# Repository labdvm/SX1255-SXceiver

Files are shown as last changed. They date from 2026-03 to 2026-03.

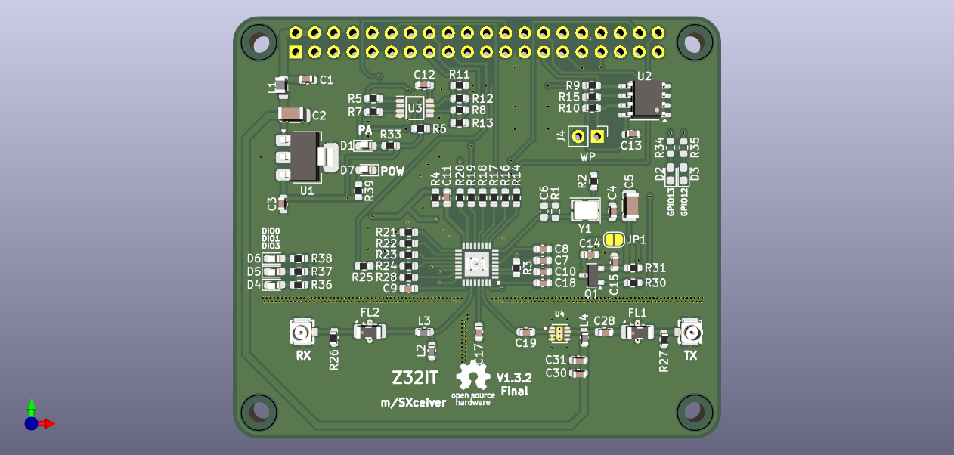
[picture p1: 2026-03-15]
SX1255-SXCEIVER-HAT.png

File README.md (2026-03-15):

# SX1255-SXceiver-HAT
This is modified SXceiver by shared schematic from Tatu Peltola.
SX1255 HAT for RPi4-5.
# Main SX-HAT is with (LowPass filters, PA and IPX connectors), second one is with (BandPass filters, PA and SMA connectors) and thirt one is with BandPass filters, ceramic antennas and without PA.
# RPi4/5 with minimum 2GB RAM, fast-write micro-sd card or upgraded with M.2 nvme drive.
# The eeprom is for HW-ID and if cannot be programmed by the procedures then you must programm with eeprom programmator. " https://github.com/tejeez/sxxcvr/blob/main/dts/README.md ".
# For Tetra-TMO Base Station this is the installing procedures, " https://github.com/MidnightBlueLabs/tetra-bluestation-docs/wiki ".
https://github.com/MidnightBlueLabs/tetra-bluestation

# The PA (TQP3M9036) can amplify up to 20dBm @ (70cm-band) 
# BlueStation Tetra TMO configurator " https://dimetra.russel053.com/ "
# Z32IT

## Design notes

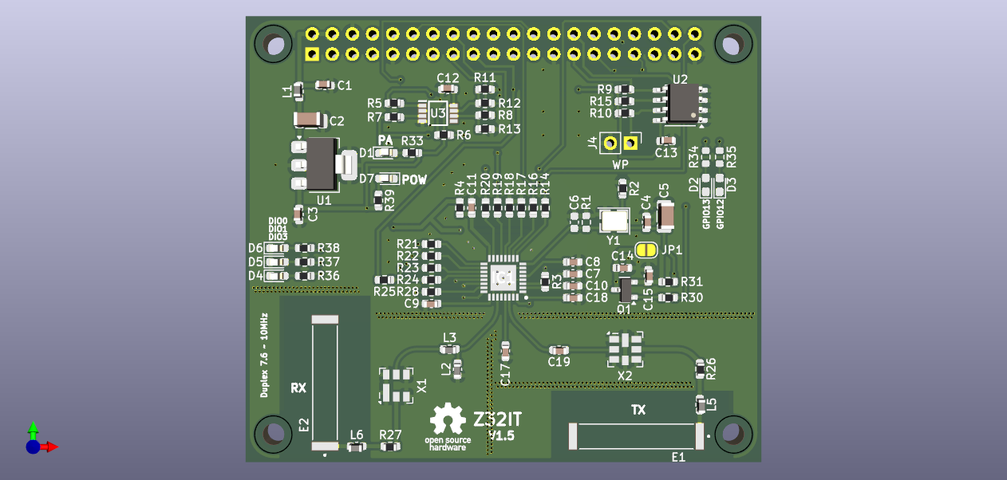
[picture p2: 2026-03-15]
SX1255-SXCEIVER-HAT_microspot/SX1255-SXCEIVER-HAT_microspot.png

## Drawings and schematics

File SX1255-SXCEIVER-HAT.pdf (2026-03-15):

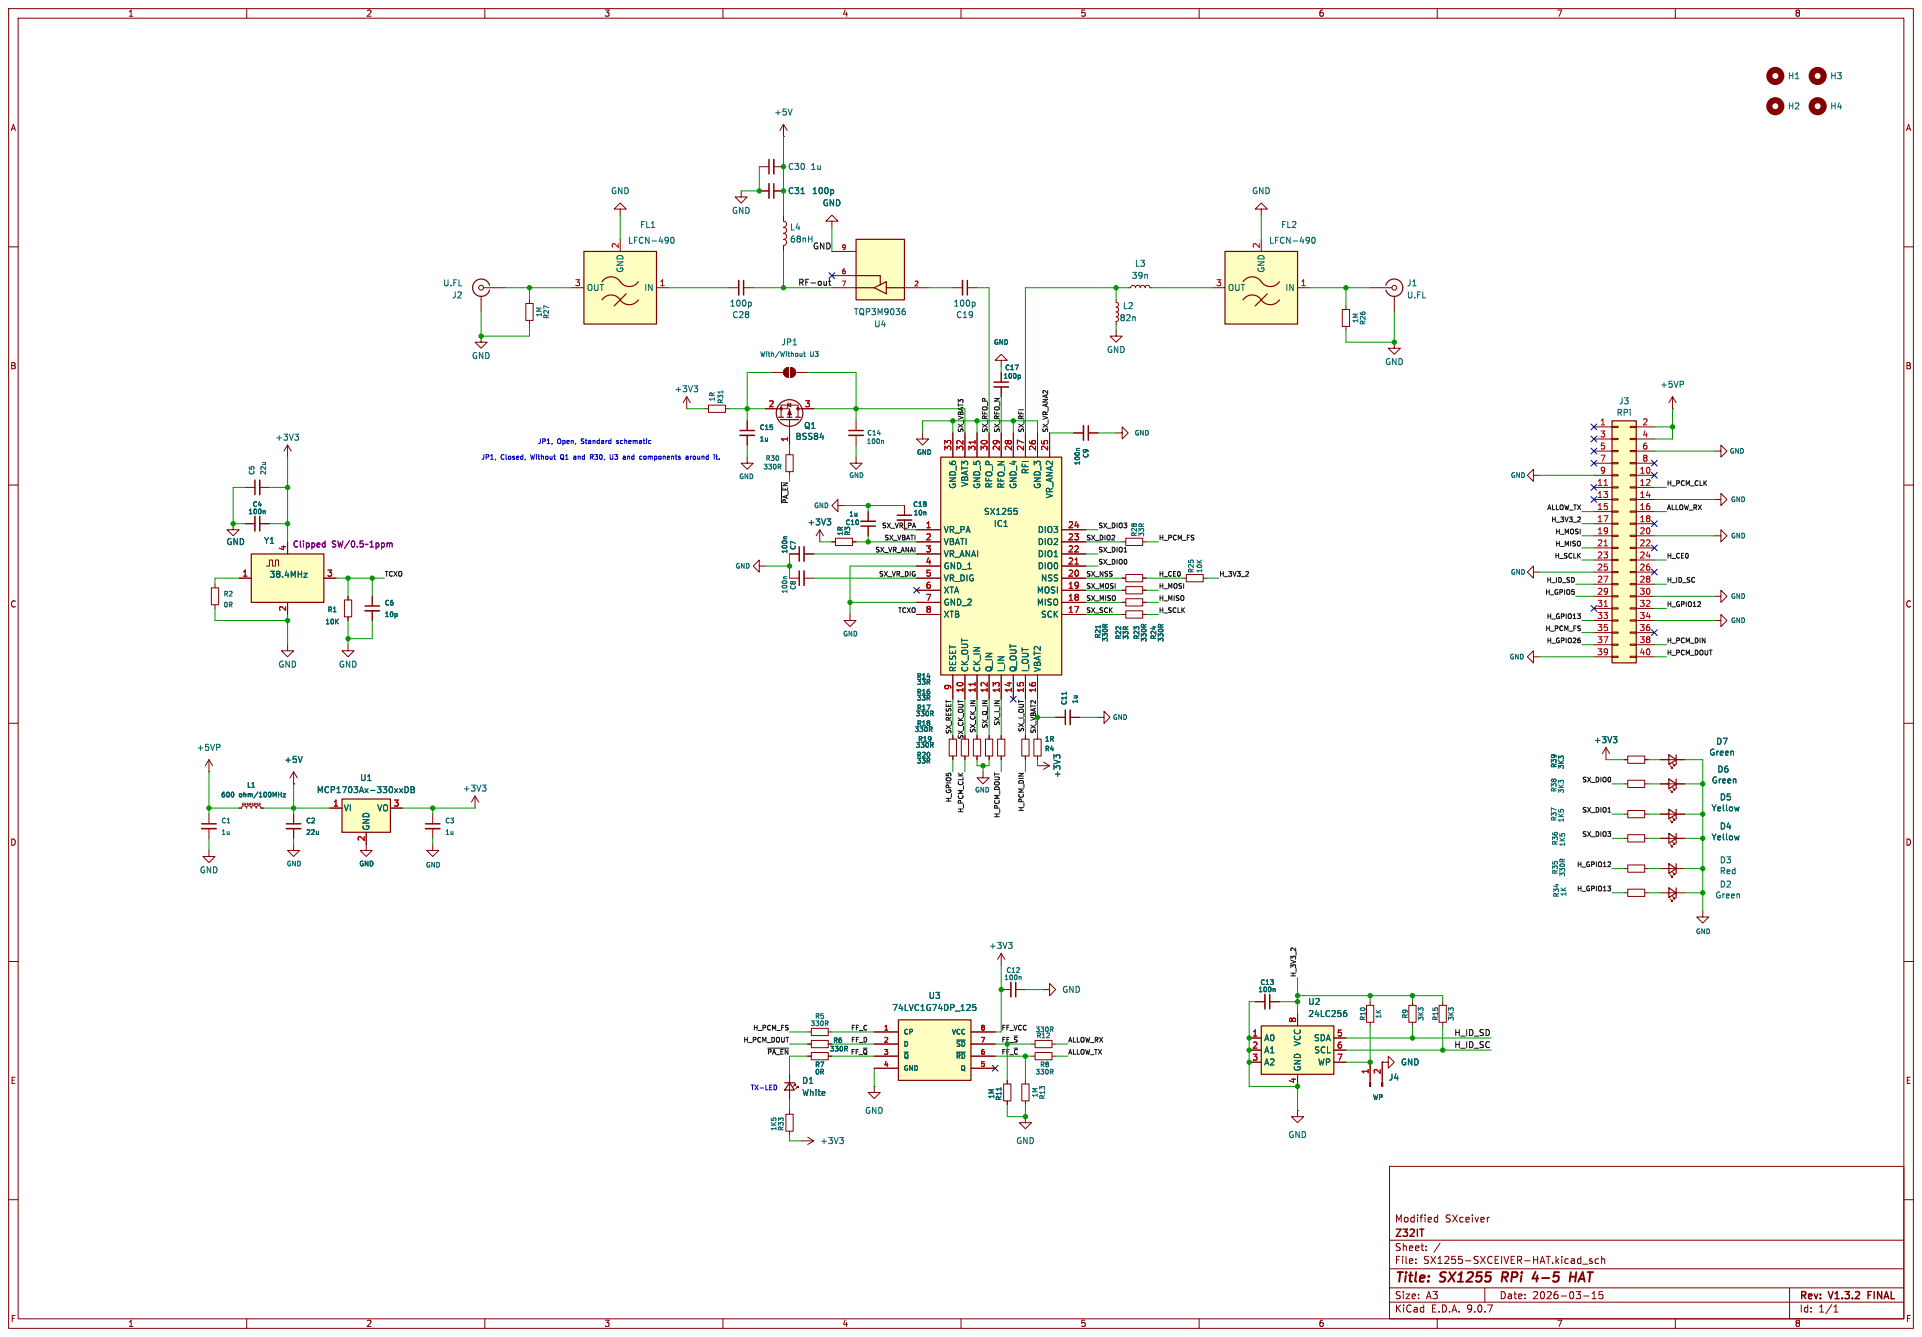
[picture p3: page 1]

9 VBAT3 32 CK_OUT 10 GND_5 31 CK_IN 11 RFO_P 30 Q_IN 12 RFO_N 29 I_IN 13 GND_4 28 Q_OUT 14 RFI 27 I_OUT 15 GND_3 26 VBAT2 16 VR_ANA2 25 DIO3 24 DIO2 23 DIO1 22 DIO0 21 NSS 20 MOSI 19 MISO 18 SCK 17

9 VBAT3 32 CK_OUT 10 GND_5 31 CK_IN 11 RFO_P 30 Q_IN 12 RFO_N 29 I_IN 13 GND_4 28 Q_OUT 14 RFI 27 I_OUT 15 GND_3 26 VBAT2 16 VR_ANA2 25 DIO3 24 DIO2 23 DIO1 22 DIO0 21 NSS 20 MOSI 19 MISO 18 SCK 17 C9 100n R23 R22 33R 330R R24 330R R21 330R GND

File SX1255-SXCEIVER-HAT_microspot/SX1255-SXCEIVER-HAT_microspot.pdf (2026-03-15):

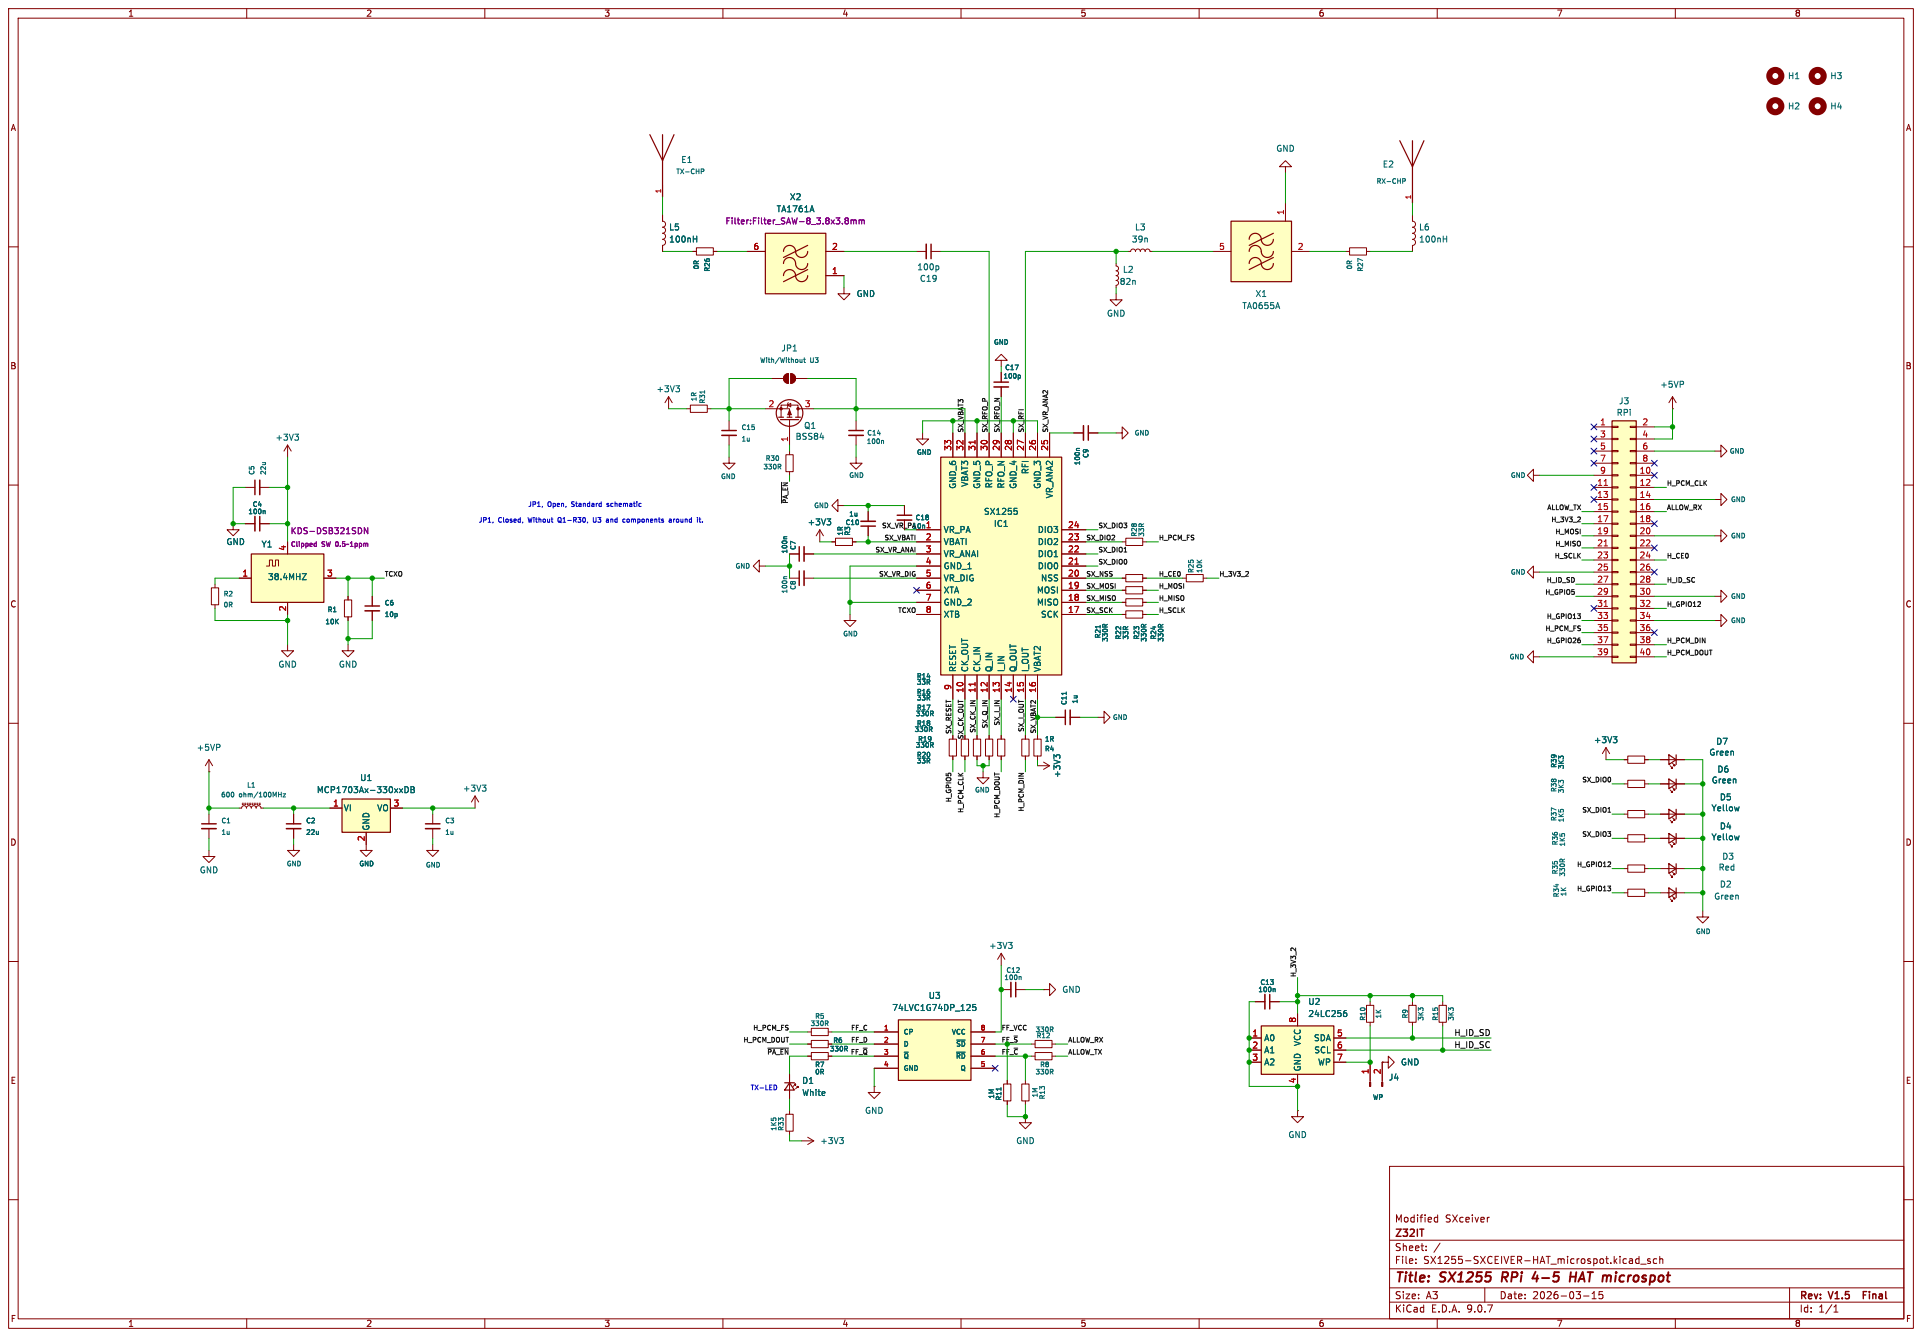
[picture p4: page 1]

9 VBAT3 32 CK_OUT 10 GND_5 31 CK_IN 11 RFO_P 30 Q_IN 12 RFO_N 29 I_IN 13 GND_4 28 Q_OUT 14 RFI 27 I_OUT 15 GND_3 26 VBAT2 16 VR_ANA2 25 DIO3 24 DIO2 23 DIO1 22 DIO0 21 NSS 20 MOSI 19 MISO 18 SCK 17 R17

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

Clipped SW 0.5~1ppm KDS-DSB321SDN GND
3 GND

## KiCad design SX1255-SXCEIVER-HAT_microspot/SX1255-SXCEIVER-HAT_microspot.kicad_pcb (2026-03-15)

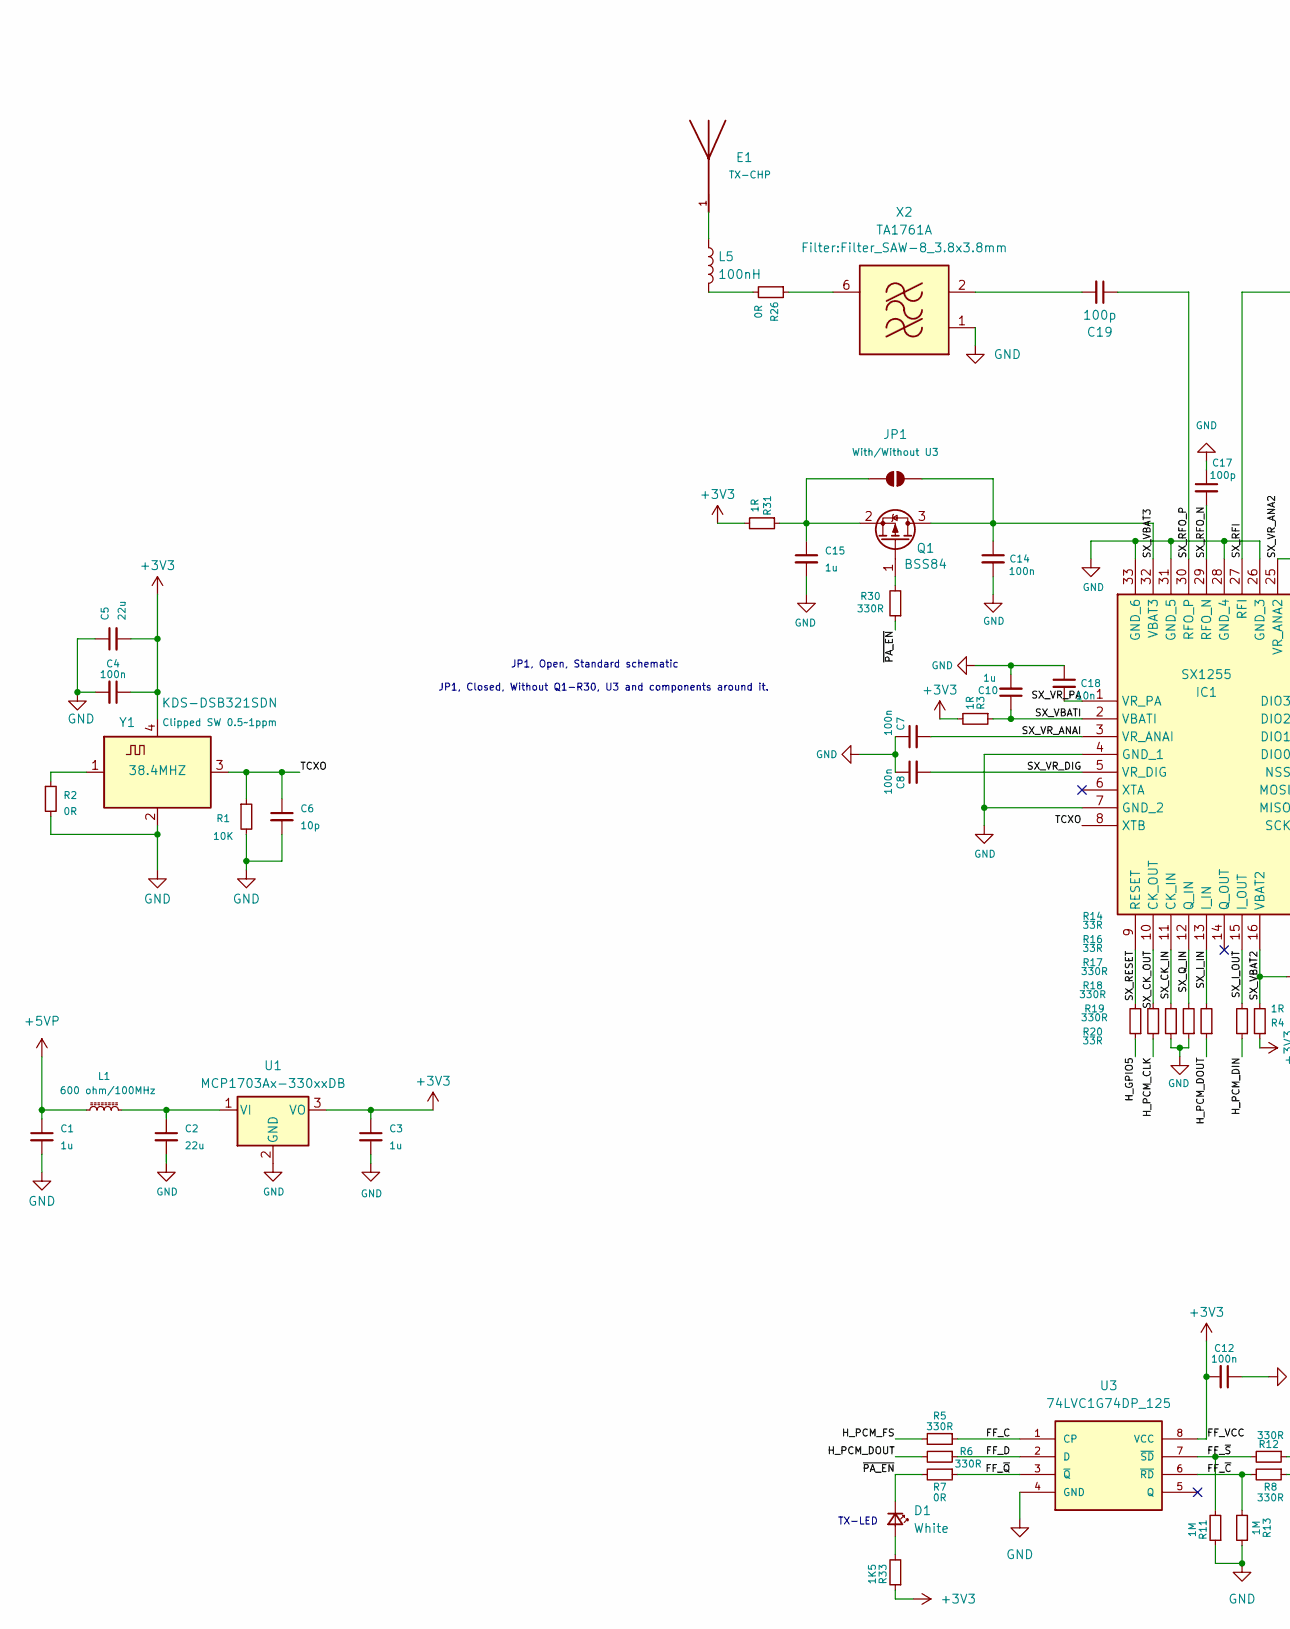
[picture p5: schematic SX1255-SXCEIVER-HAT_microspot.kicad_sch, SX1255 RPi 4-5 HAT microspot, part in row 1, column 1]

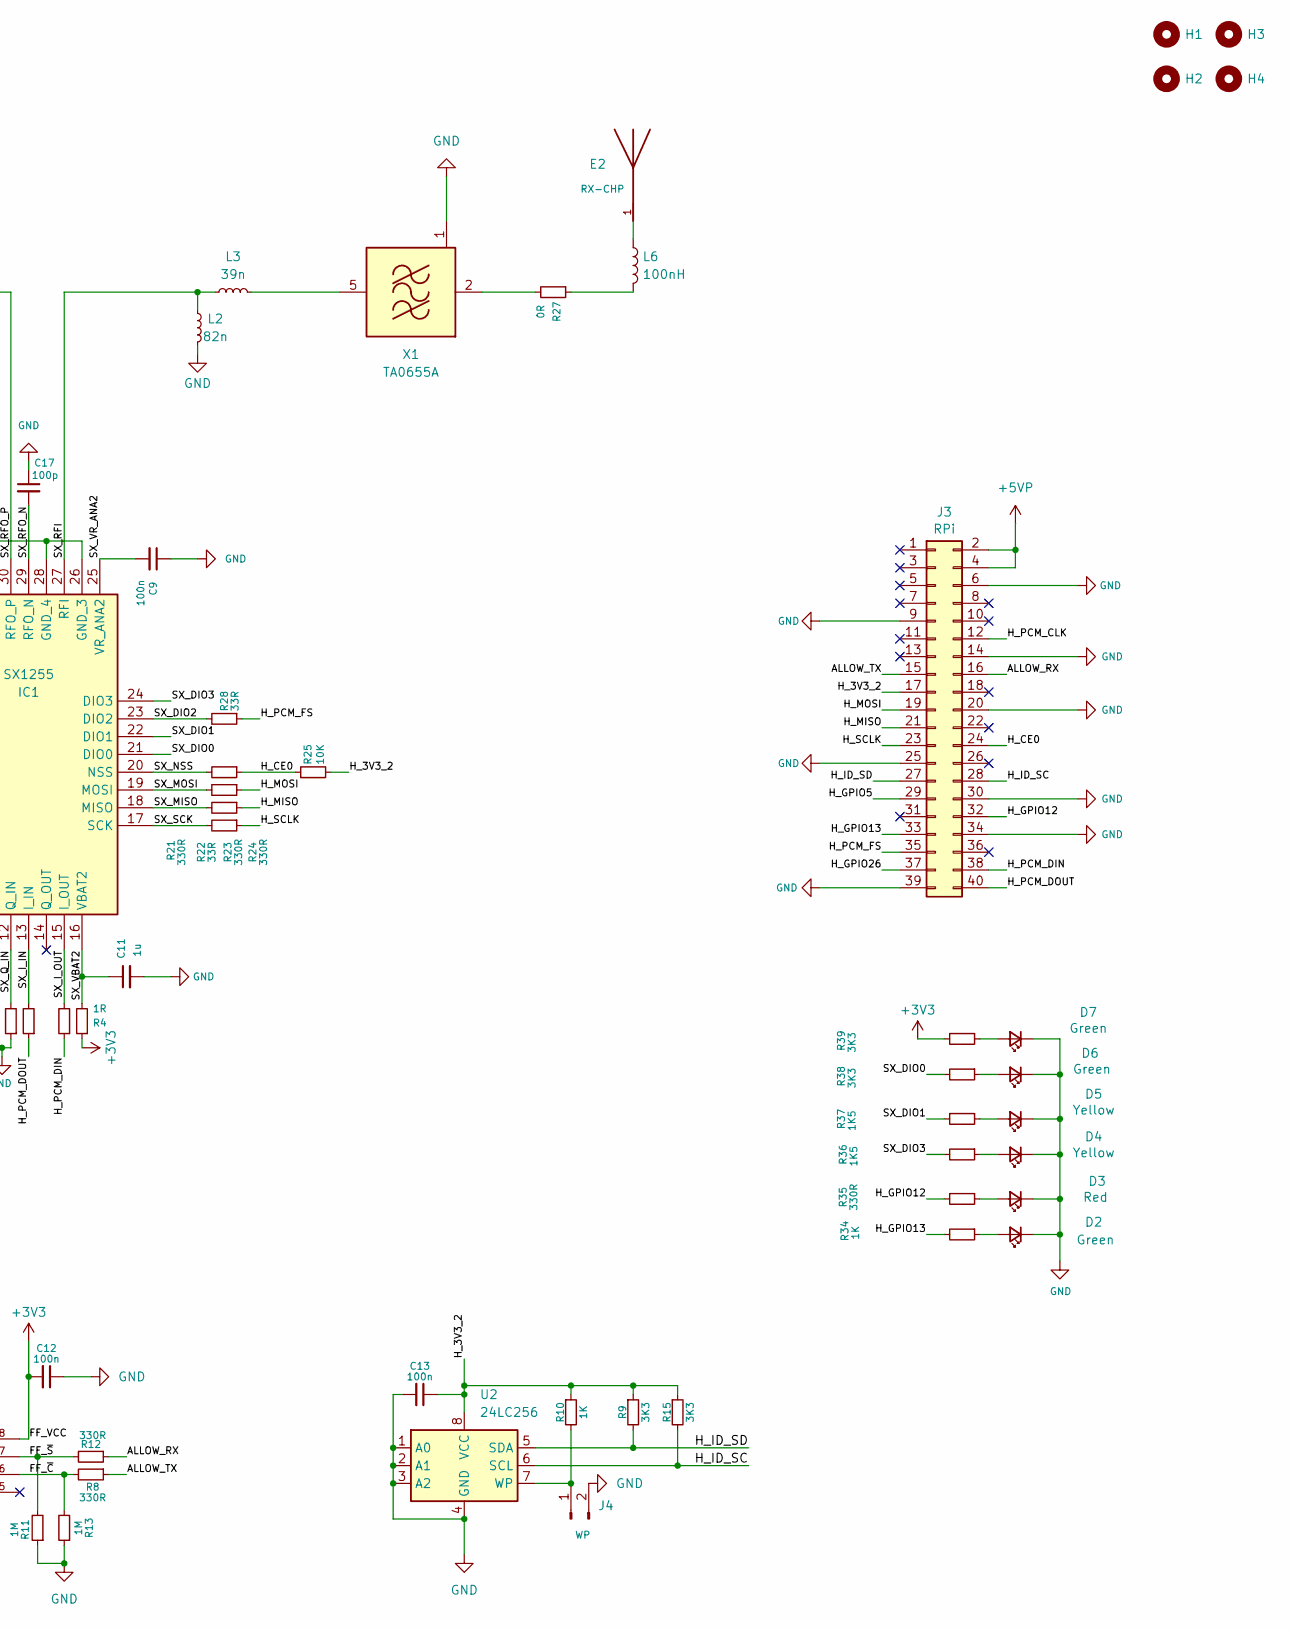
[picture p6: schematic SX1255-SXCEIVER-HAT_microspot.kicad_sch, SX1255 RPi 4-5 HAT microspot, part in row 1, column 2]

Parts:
C1, C3, C10, C11, C15: 1u; C_0603_1608Metric
C2, C5: 22u; C_1206_3216Metric
C4, C7, C8, C9, C12, C13, C14: 100n; C_0603_1608Metric
C6: 10p; C_0603_1608Metric
C17, C19: 100p; C_0603_1608Metric
C18: 10n; C_0603_1608Metric
D1: White; LED_0603_1608Metric_Pad1.05x0.95mm_HandSolder
D2, D6, D7: Green; LED_0603_1608Metric_Pad1.05x0.95mm_HandSolder
D3: Red; LED_0603_1608Metric_Pad1.05x0.95mm_HandSolder
D4, D5: Yellow; LED_0603_1608Metric_Pad1.05x0.95mm_HandSolder
E1: TX-CHP; XDCR_ANT-868-CHP-T; PARTREV C
E2: RX-CHP; XDCR_ANT-868-CHP-T; PARTREV C
H1, H2, H3, H4: MountingHole; MountingHole_2.7mm_M2.5_DIN965
IC1: SX1255; QFN50P500X500X80-33N-D; MPN SX1255IWLTRT
J3: RPi; PinSocket_2x20_P2.54mm_Vertical
J4: WP; PinHeader_1x02_P2.54mm_Vertical
JP1: With/Without U3; SolderJumper-2_P1.3mm_Open_RoundedPad1.0x1.5mm
L1: 600 ohm/100MHz; L_0603_1608Metric
L2: 82n; L_0603_1608Metric
L3: 39n; L_0603_1608Metric
L5, L6: 100nH; L_0603_1608Metric
Q1: BSS84; SOT-23
R1, R25: 10K; R_0603_1608Metric
R2, R7, R26, R27: 0R; R_0603_1608Metric
R3, R4, R31: 1R; R_0603_1608Metric
R5, R6, R8, R12, R17, R18, R19, R21, R23, R24, R30, R35: 330R; R_0603_1608Metric
R9, R15, R38, R39: 3K3; R_0603_1608Metric
R10, R34: 1K; R_0603_1608Metric
R11, R13: 1M; R_0603_1608Metric
R14, R16, R20, R22, R28: 33R; R_0603_1608Metric
R33, R36, R37: 1K5; R_0603_1608Metric
U1: MCP1703Ax-330xxDB; SOT-223-3_TabPin2
U2: 24LC256; SOIC-8_3.9x4.9mm_P1.27mm
U3: 74LVC1G74DP_125; SOP65P400X110-8N; MOUSER_PART_NUMBER 771-LVC1GDP125
X1: TA0655A; Filter_SAW-6_3.8x3.8mm
X2: TA1761A; Filter_SAW-8_3.8x3.8mm
Y1: 38.4MHZ; Crystal_SMD_3225-4Pin_3.2x2.5mm

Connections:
+3V3: C3.1, C4.1, C5.2, C12.2, R3.2, R4.1, R31.2, R33.1, R39.2, U1.3 (VO), U3.8 (VCC), Y1.4 (VDD)
+5VP: C1.1, J3.2, J3.4, L1.1
/ALLOW_RX: J3.16, R12.1
/ALLOW_TX: J3.15, R8.1
/FF_C: R5.1, U3.1 (CP)
/FF_D: R6.1, U3.2 (D)
/FF_~C: R8.2, R13.2, U3.6 (~RD)
/FF_~Q: R7.1, U3.3 (~Q)
/FF_~S: R11.2, R12.2, U3.7 (~SD)
/H_3V3_2: C13.1, J3.17, R9.1, R10.1, R15.1, R25.2, U2.8 (VCC)
/H_CE0: J3.24, R24.1, R25.1
/H_GPIO5: J3.29, R14.1
/H_GPIO12: J3.32, R35.2
/H_GPIO13: J3.33, R34.2
/H_GPIO26: J3.37
/H_ID_SC: J3.28, R15.2, U2.6 (SCL)
/H_ID_SD: J3.27, R9.2, U2.5 (SDA)
/H_MISO: J3.21, R22.1
/H_MOSI: J3.19, R23.1
/H_PCM_CLK: J3.12, R16.1
/H_PCM_DIN: J3.38, R20.1
/H_PCM_DOUT: J3.40, R6.2, R19.1
/H_PCM_FS: J3.35, R5.2, R28.1
/H_SCLK: J3.23, R21.1
/SX_CK_IN: IC1.11 (CK_IN), R17.2
/SX_CK_OUT: IC1.10 (CK_OUT), R16.2
/SX_DIO0: IC1.21 (DIO0), R38.2
/SX_DIO1: IC1.22 (DIO1), R37.2
/SX_DIO2: IC1.23 (DIO2), R28.2
/SX_DIO3: IC1.24 (DIO3), R36.2
/SX_I_IN: IC1.13 (I_IN), R19.2
/SX_I_OUT: IC1.15 (I_OUT), R20.2
/SX_MISO: IC1.18 (MISO), R22.2
/SX_MOSI: IC1.19 (MOSI), R23.2
/SX_NSS: IC1.20 (NSS), R24.2
/SX_Q_IN: IC1.12 (Q_IN), R18.2
/SX_RESET: IC1.9 (RESET), R14.2
/SX_RFI: IC1.27 (RFI), L2.2, L3.2
/SX_RFO_N: C17.2, IC1.29 (RFO_N)
/SX_RFO_P: C19.1, IC1.30 (RFO_P)
/SX_SCK: IC1.17 (SCK), R21.2
/SX_VBAT2: C11.1, IC1.16 (VBAT2), R4.2
/SX_VBAT3: C14.1, IC1.32 (VBAT3), JP1.2 (B), Q1.3 (D)
/SX_VBATI: C10.1, IC1.2 (VBATI), R3.1
/SX_VR_ANA2: C9.2, IC1.25 (VR_ANA2)
/SX_VR_ANAI: C7.2, IC1.3 (VR_ANAI)
/SX_VR_DIG: C8.2, IC1.5 (VR_DIG)
/SX_VR_PA: C18.2, IC1.1 (VR_PA)
/TCXO: C6.1, IC1.8 (XTB), R1.1, Y1.3 (OUT)
/~PA_EN: D1.1 (K), R7.2, R30.1
GND: C1.2, C2.2, C3.2, C4.2, C5.1, C6.2, C7.1, C8.1, C9.1, C10.2, C11.2, C12.1, C13.2, C14.2, C15.2, C17.1, C18.1, D2.1 (K), D3.1 (K), D4.1 (K), D5.1 (K), D6.1 (K), D7.1 (K), IC1.4 (GND_1), IC1.7 (GND_2), IC1.26 (GND_3), IC1.28 (GND_4), IC1.31 (GND_5), IC1.33 (GND_6), J3.6, J3.9, J3.14, J3.20, J3.25, J3.30, J3.34, J3.39, J4.2, L2.1, R1.2, R2.2, R11.1, R13.1, R17.1, R18.1, U1.2 (GND), U2.1 (A0), U2.2 (A1), U2.3 (A2), U2.4 (GND), U3.4 (GND), X1.1 (GND), X1.3 (GND), X1.4 (GND), X1.6 (GND), X2.1 (GND), X2.3 (GND), X2.4 (GND), X2.5 (GND), X2.7 (GND), X2.8 (GND), Y1.2 (GND)
unnamed: D1.2 (A), R33.2
unnamed: D2.2 (A), R34.1
unnamed: D3.2 (A), R35.1
unnamed: D4.2 (A), R36.1
unnamed: D5.2 (A), R37.1
unnamed: D6.2 (A), R38.1
unnamed: D7.2 (A), R39.1
unnamed: E1.1, L5.1
unnamed: E2.1, L6.1
unnamed: J4.1, R10.2, U2.7 (WP)
unnamed: C15.1, JP1.1 (A), Q1.2 (S), R31.1
unnamed: L5.2, R26.2
unnamed: L6.2, R27.1
unnamed: Q1.1 (G), R30.2
unnamed: C2.1, L1.2, U1.1 (VI)
unnamed: R27.2, X1.2 (IN)
unnamed: L3.1, X1.5 (OUT)
unnamed: C19.2, X2.2 (RF_In)
unnamed: R26.1, X2.6 (RF_out)
unnamed: R2.1, Y1.1 (Tri-State)

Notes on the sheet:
TX-LED
JP1, Open, Standard schematic
JP1, Closed, Without Q1-R30, U3 and components around it.

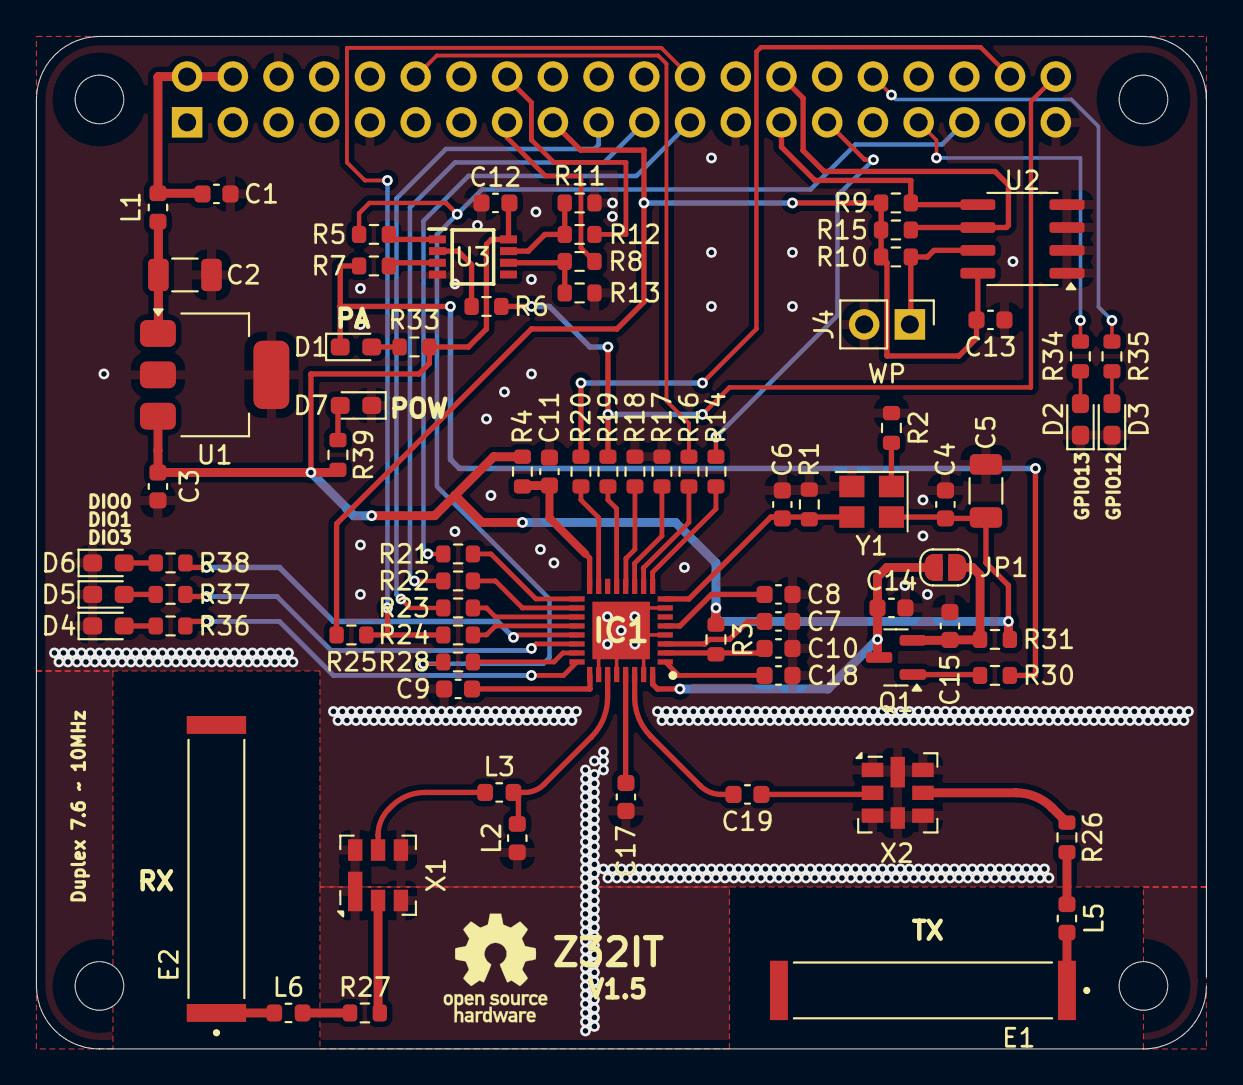
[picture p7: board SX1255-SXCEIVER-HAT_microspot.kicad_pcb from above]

Board: 2 copper layers, 65.0 x 56.2 mm, 84 parts (1 on the bottom side), 70 nets.

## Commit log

2026-02-28 Update README with RPi4-5 recommendations
    Added hardware recommendations for Raspberry Pi.
2026-03-02 Add files via upload
    The BOM file is empty !!!
    [SX1255-SXCEIVER-HAT.kicad_pcb_bom.csv, SX1255-SXCEIVER-HAT.kicad_pcb_positions.csv]
